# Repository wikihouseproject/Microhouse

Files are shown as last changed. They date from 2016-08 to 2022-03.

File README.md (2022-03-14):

### IMPORTANT: This repo uses an outdated, unsupported WikiHouse system. For the latest WikiHouse core system info please see the [Skylark repo](https://github.com/wikihouseproject/Skylark) and [WikiHouse guides](https://www.wikihouse.cc/guides)

# Microhouse 

MicroHouse is a high-performance, one-bed house type, designed using the WikiHouse Wren building system. It has been designed primarily for use in the UK, but could also be adapted for other countries and regions. The home can be largely self-assembled, and costs around £37-45k GBP to produce. 

These files are also intended as starter files for architects, designers, engineers and others interested in getting to know how to use the WikiHouse WREN system within a full design.

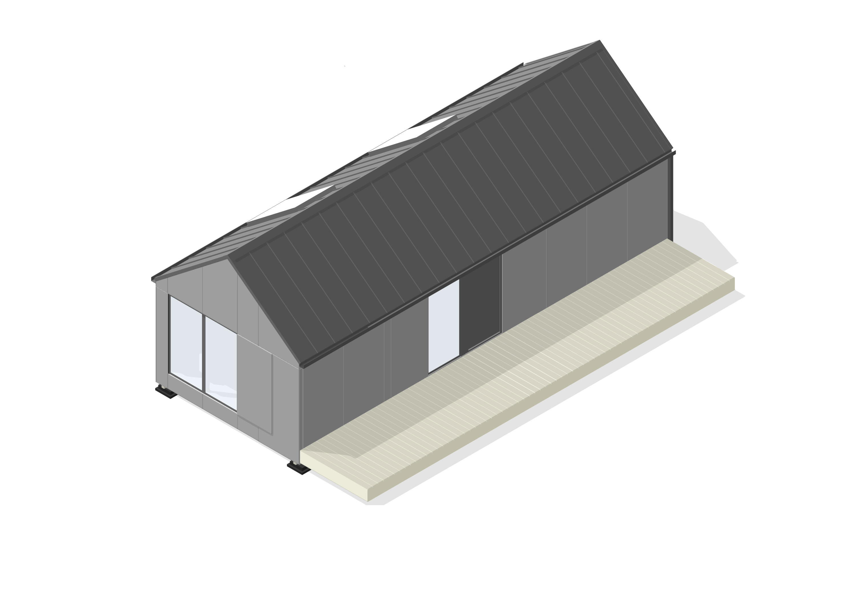
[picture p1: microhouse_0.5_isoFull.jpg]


_Project Engine: contains specification, costing/quantity information, and overall dimensions of the Microhouse design

_AssemblyManual: Detailed guide on how to put the whole thing together

_othercomponents_v0.5.dxf: Additional CNC cutting files for other components, such as fit-out furniture using SPARROW and cladding panels.

_WRENchassis_v0.5.dxf: Complete CNC cutting files for the building's structural chassis

_microhouse_0.5.skp: Sketchup 3D Model of the complete design including cladding, fitout and services

_microhouse_0.5_chassis.skp: Sketchup 3D Model of the Wikihouse structural chassis

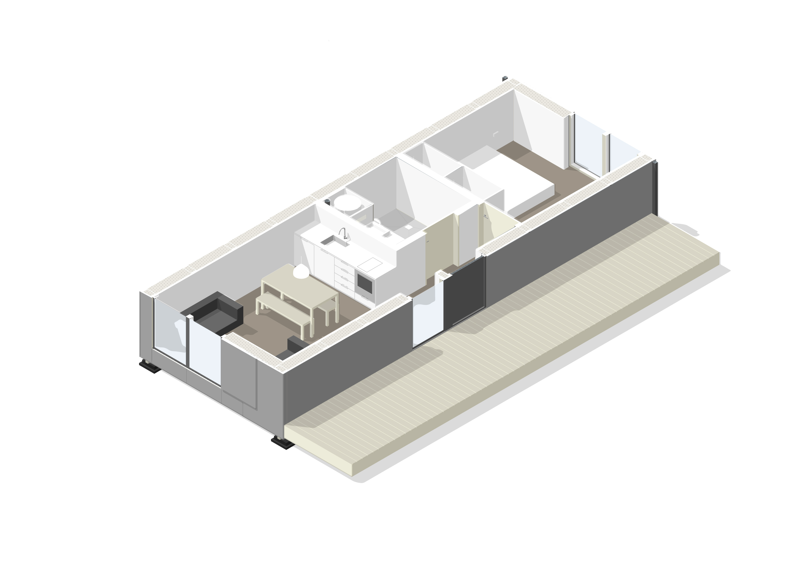
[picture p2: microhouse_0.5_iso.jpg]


<div class="sketchfab-embed-wrapper"><iframe width="640" height="480" src="https://sketchfab.com/models/ac3263022fca412c934ea9dd7c5b5521/embed" frameborder="0" allowfullscreen mozallowfullscreen="true" webkitallowfullscreen="true" onmousewheel=""></iframe>

<p style="font-size: 13px; font-weight: normal; margin: 5px; color: #4A4A4A;">
    <a href="https://sketchfab.com/models/ac3263022fca412c934ea9dd7c5b5521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" target="_blank" style="font-weight: bold; color: #1CAAD9;">Microhouse</a>
    by <a href="https://sketchfab.com/wikihouseproject?utm_medium=embed&utm_source=website&utm_campain=share-popup" target="_blank" style="font-weight: bold; color: #1CAAD9;">wikihouseproject</a>
    on <a href="https://sketchfab.com?utm_medium=embed&utm_source=website&utm_campain=share-popup" target="_blank" style="font-weight: bold; color: #1CAAD9;">Sketchfab</a>
</p>
</div>

# Terms of use

By downloading these files or information you agree to the following terms and conditions.

Information is shared without any kind of warranty or guarantee
All Information is provided ‘as is’. No representations or warranties express or implied are made regarding the Wikihouse Info, its accuracy, completeness, functionality or fitness for a particular use in a particular location.  

You are solely responsible for the use of the information
By using this information you assume full responsibility for any loss resulting from use or inability to use the Wikihouse Info, and forever releases WikiHouse Foundation or other WikiHouse users from any liability for such loss;  including but not limited to loss of profits, goodwill or assets.

You are responsible for meeting local codes and legislation
Users must satisfy themselves regarding the application of statutory requirements, local building regulations, codes, insurance certification or other requirements or recommendations relevant to the location where and materials with which they plan to build. Where required you should always seek the advice of a relevant qualified professional.

You are responsible for using the information in a safe way
 Users are responsible for ensuring that information they use or cause to be used is used in a way which is safe, and is not likely to cause harm during or after manufacturing, construction, use or disassembly.

=======
<br />This work is licensed under a <a rel="license" href="http://creativecommons.org/licenses/by-sa/3.0/">Creative Commons Attribution-ShareAlike 3.0 Unported License</a>.

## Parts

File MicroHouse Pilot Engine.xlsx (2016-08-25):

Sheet: Specification
MicroHouse
Date | 2016 |  |  |  |  |  |  |  |  |  |  |  | Estimate figure
Country | United Kingdom |  |  |  |  |  |  |  |  |  |  |  | Expected figure
Client | None |  |  |  |  |  |  |  |  |  |  |  | Actual / locked-in figure
Project use | Dwelling
Project design | Architecture 00 |  |  |  |  |  |  |  |  |  |  |  | Key action / info / check needed
WikiHouse open products used | Wren |  |  |  |  |  |  |  |  |  |  |  | Manufacturing needed
Status | Template |  |  |  |  |  |  |  |  |  |  |  | Ready to procure
Gross internal area (m2) | 37.6 m2 |  |  |  |  |  |  |  |  |  |  |  | Procured
Site address | n/a |  |  |  |  |  |  |  |  |  |  |  | Alternative option (not included in total)
MATERIAL |  |  | by Measurement |  |  |  | by Quantity |  |  | Cost |  |  | Total
Item | Specification | Suggested | Amount required | Unit | £ per SqM / M | Sub total cost | # Units per M, SqM or CuM | Total # Units | £ per Unit | TOTAL £ | VAT @ 20%
SITE & LANDSCAPE
Site clearing |  |  |  |  |  |  |  |  |  | £0.00 | £0.00
Site services installation |  |  |  |  |  |  |  |  |  | £0.00 | £0.00
Landscaping |  |  |  |  |  |  |  |  |  | £0.00 | £0.00
SUB TOTAL |  |  |  |  |  |  |  |  |  | £0.00 | £0.00
FOUNDATIONS / FOOTINGS
Pad foundations | eg. Jackpad, Swiftpad, Easypad | http://jackpad.co.uk/ | 12 |  |  |  |  | 12 | £80.00 | £960.00 | £192.00
Rail joists | 75 x 200 x 4800 treated timber | https://www.travisperkins.co.uk/Sawn-Timber-Regularised-Treated-C16-75mm-x-200mm-x-4-8m/p/322920#b | 5 |  |  |  |  | 5 | £50.00 | £250.00 | £50.00
Damp proof course roll |  | http://www.wickes.co.uk/Visqueen-Polythene-Damp-Proof-Course-300mm-x-30m/p/226581 | 22.00 | m |  |  |  | 1 | £8.32 | £8.33 | £1.67
Jointing plates | Zinc plated steel | http://www.wickes.co.uk/Wickes-Galvanised-Jointing-Flat-Plate-63x300mm/p/152829 | 4 |  |  |  |  | 4 | £2.95 | £11.80 | £2.36
Bolting brackets | Heavy Duty Angle Bracket 60mm x 60mm | http://www.screwfix.com/p/sabrefix-heavy-duty-angle-brackets-galvanised-60-x-50mm-10-pack/61576 | 16 | No. |  |  |  | 2 | £6.99 | £13.98 | £2.80
Rodent Mesh |  |  |  |  |  |  |  |  |  | £0.00 | £0.00
SUB TOTAL |  |  |  |  |  |  |  |  |  | £1,244.11 | £248.82
CHASSIS
Structural panel | WISA Spruce Plywood | 18mm x 2440 x1220 |  |  |  |  |  | 225 | £22.30 | £5,017.50 | £1,003.50
50mm screws | Prodrive Recess Countersunk Screws 200pk |  |  |  |  |  |  | 2500 | £0.00 | £0.00 | £0.00
30mm screws | Prodrive Recess Countersunk Screws |  |  |  |  |  |  | 2500 | £0.00 | £0.00 | £0.00
Underboarding | 12mm x 2400 x1200 WBP plywood |  | 39.24 | m2 |  |  |  | 10 | £16.67 | £166.67 | £33.33
SUB TOTAL |  |  |  |  |  |  |  |  |  | £5,184.17 | £1,036.83
INSULATION & AIRTIGHTNESS
Wall and roof insulation layer 1 | Soft-Fill wool/recycled - 150mm | http://www.insulationexpress.co.uk/Loft-Insulation/150mm-Earthwool-Loft-Roll-44-%28Combi-Cut%29-Loft-Insulation.htm | 42.10 | m3 |  |  |  | 11 | £24.79 | £272.69 | £54.54
Wall and roof insulation layer 2 | Soft-Fill wool/recycled - 100mm | http://www.insulationexpress.co.uk/Loft-Insulation/100mm-Earthwool-Loft-Roll-44-%28Combi-Cut%29-Loft-Insulation.htm | 58.09 | m3 |  |  |  | 10 | £26.25 | £262.50 | £52.50
Floor insulation | Cellulose loose fill | http://www.ecomerchant.co.uk/roofing/insulation/cellulose/thermofloc-loose-fill-cellulose-insulation-12kg.html | 13.32 | m3 |  |  | 3.33 | 44 | £11.99 | £531.82 | £106.36
Vapour barrier tape | Tescon | http://www.ecomerchant.co.uk/walls/airtightness-products/airtightness-tapes/pro-clima-tescon-vana.html |  |  |  |  |  | 5 | £22.50 | £112.50 | £22.50
Vapour barrier | Intello | http://www.ecomerchant.co.uk/walls/airtightness-products/internal-membranes/pro-clima-intello-plus-1-5x20m.html | 130.00 | m2 |  |  |  | 5 | £61.60 | £308.00 | £61.60
Service penetration collars
SUB TOTAL |  |  |  |  |  |  |  |  |  | £1,487.51 | £297.50
EXTERNAL WRAP
Breather membrane | Tyvek supro or similar | https://www.roofingsuperstore.co.uk/product/tyvek-supro-15m-x-50m.html | 143.00 | m2 |  |  | 0.01538 | 3 | £94.37 | £283.11 | £56.62
Heavy duty staples | Any size to fit staple gun | http://www.wickes.co.uk/Stanley-Heavy-Duty-Staples-8mm-Pack-1000/p/226059 |  |  |  |  |  | 2 | £2.90 | £5.80 | £1.16
SUB TOTAL |  |  |  |  |  |  |  |  |  | £288.91 | £57.78
CLADDING
Battens | 25mm treated batten | http://www.wickes.co.uk/Wickes-Treated-Roof-Batten-25x50x3600mm-Pack-8/p/133670 | 162 | m |  |  |  | 6 | £22.49 | £134.94 | £26.99
Opt 1 Stokboard panels | 9mm x 1220 x240 | http://www.kedel.co.uk/recycled-plastic-sheet/stokbord-recycled-plastic-sheet-board.html | 89.00 | m2 |  |  |  | 31 | £40.26 | £1,248.06 | £249.61
Opt 2 Timber cladding |  | http://www.uk-timber.co.uk/english-larch-external-half-lap-cladding-timber-p-283.html | 89.00 |  | £26.00 |  |  |  |  | £2,314.00 | £462.80
Opt 3 Steel panels | Tata colorcoat urban |  | 89.00 | m2 | £20.00 |  |  |  | £1,780.00 | £1,780.00 | £356.00
Cladding fixings |  |  |  |  |  |  |  |  | £0.00 | £0.00 | £0.00
Shutter hinges
SUB TOTAL |  |  |  |  |  |  |  |  |  | £1,383.00 | £276.60
ROOFING
Roofing Material | Steel Profile panels 514 x 2720 | TATA Colorcoat Urban | 58.09 | m2 | £20.00 |  |  | 36 | £0.00 | £1,161.83 | £232.37
Roof flashings (below rooflights) | To match roof 1330 x320
Ridge capping | Colour to match roof | TATA Colorcoat Urban | 10.8 | m |  |  |  |  | £0.00 | £0.00 | £0.00
Edge flashing | To match roof | TATA Colorcoat Urban | 10.6 | m |  |  |  |  | £0.00 | £0.00 | £0.00
Vent pipe collar
Eave fillers |  |  |  |  |  |  |  |  | £0.00 | £0.00 | £0.00
Gutter | To match roof 3m lengths | https://www.tatasteelconstruction.com/en_GB/Products/Building-envelope/Ancillaries/Fascias-and-gutters/Rainwater-Systems | 21.9 | m |  |  |  | 8 | £0.00 | £0.00 | £0.00
Gutter joins |  |  | 6
Gutter ends |  |  | 2
Gutter hoppers |  |  | 2
Gutter brackets |  |  | 44
Downpipe |  |  | 4.8 | m |  |  |  |  | £0.00 | £0.00 | £0.00
SUB TOTAL |  |  |  |  |  |  |  |  |  | £1,161.83 | £232.37
WINDOWS & DOORS
External door | ideal combi futura+i or similar | https://idealcombi.dk/Flippingbook/UK_FuturaPlus_Install2014.pdf |  |  |  |  |  | 1 | £250.00 | £250.00 | £50.00
External windows 1 | ideal combi futura+i or similar, to fit opening 2100mm x 2100mm |  |  |  |  |  |  | 2 | £1280.00 | £2,560.00 | £512.00
External windows 2 | ideal combi futura+i or similar, to fit opening 1050mm x 2100mm |  |  |  |  |  |  | 1 | £680.00 | £680.00 | £136.00
Rooflight | Openable rooflight, Internal size 920 x 1570 | https://roof-maker.co.uk/luxlite-15-70-degree-rooflight/ | 2 |  |  |  |  | 2 | £860.00 | £1,720.00 | £344.00
Expanding seal tape | Ensure correct gap size | http://www.ecomerchant.co.uk/exterior/compression-tapes/vitaseal-expanding-foam-compression-tape.html | 30 | M | £4.00 |  |  |  | £0.00 | £120.00 | £24.00
Window flashing tape |  | http://www.ecomerchant.co.uk/extoseal-encors-water-bearing-adhesive-connection-tape-with-high-adhesion-strength.html | 30 | M |  |  |  | 2.00 | £53.75 | £107.50 | £21.50
SUB TOTAL |  |  |  |  |  |  |  |  |  | £5,330.00 | £1,066.00
INTERNAL LINING
Battens for walls and ceiling | 25mm roofing batten | http://www.wickes.co.uk/Wickes-Treated-Roof-Batten-25x50x3600mm-Pack-8/p/133670 | 129 | m | £0.94 |  |  | 5 | £22.49 | £112.45 | £22.49
Gypsum wall board | Plasterboard with tapered edge | http://www.insulationexpress.co.uk/Product.asp?gclid=CPy6r9byls4CFdQ_GwodiJYNyQ | 80.99 | m2 |  |  |  | 53 | £10.51 | £557.03 | £111.41
Plasterboard screws |  |  |  |  |  |  |  |  | £0.00 | £0.00 | £0.00
Wall board filler |  |  |  |  |  |  |  |  | £0.00 | £0.00 | £0.00
Wall board tape
Floor overboarding | 18mm Chipboard flooring | http://www.wickes.co.uk/Wickes-Chipboard-Loft-Panels-Pack-3/p/116420 | 37.50 | m2 | £5.68 |  |  | 32 | £5.54 | £177.28 | £35.46
SUB TOTAL |  |  |  |  |  |  |  |  |  | £669.48 | £133.90
VENTILATION SYSTEM
MVHR Unit |  | https://www.electrical2go.co.uk/ventilation/heat-recovery/multivent/monsoon-multivent-heat-recovery-units.html |  |  |  |  |  | 1 | £661.67 | £661.67 | £132.33
Distribution splitter |  | http://www.fantronix.com/acatalog/Ventilation_Ducting_-_Y_Joint.html |  |  |  |  |  | 4 | £7.52 | £30.07 | £6.01
Ductwork | 125mm | https://www.electrical2go.co.uk/semi-rigid-aluminium-round-duct-125mm-x-3m-503230.html |  |  |  |  |  | 6 | £13.09 | £78.55 | £15.71
Room vents | 125mm | https://www.electrical2go.co.uk/125mm-air-extract-supply-valve-to-fit-pipe-round-sockets-136-5.html |  |  |  |  |  | 6 | £8.57 | £51.42 | £10.28
Duct clips |  |  |  |  |  |  |  | 16 | £1.81 | £28.96 | £5.79
SUB TOTAL |  |  |  |  |  |  |  |  |  | £850.66 | £170.13
WET SERVICES
Concealed cistern |  | http://www.wickes.co.uk/Fluidmaster-Concealed-Cistern/p/138313 |  |  |  |  |  |  |  | £50.00 | £10.00
Water supply and pipes | Push fit pipes and connectors | http://www.screwfix.com/p/floplast-pe-x-barrier-pipe-white-22mm-x-25m/38914 |  |  |  |  |  |  |  | £100.00 | £20.00
Electric water heater | Heatrae Sadia Eco 170 | http://www.directheatingsupplies.co.uk/heatrae-megaflo-eco-dd170-170l-direct-unvented-cylinder |  |  |  |  |  |  |  | £665.00 | £133.00
Drain and soil pipe parts | 110mm, black, including air admittance valve |  |  |  |  |  |  |  |  | £200.00 | £0.00
SUB TOTAL |  |  |  |  |  |  |  |  |  | £1,015.00 | £203.00
ELECTRICS & LIGHTING
Energy monitor console |  |  |  |  |  |  |  |  |  | £0.00 | £0.00
Underfloor electric heating system | Warmup | http://www.warmup.co.uk/products/electric-underfloor-heating/foil-heater-system/ | 16 | M2 | £64.00 |  |  |  |  | £1,024.00 | £204.80
Electric heating towel rail |  | http://www.bestheating.com/kudox-chrome-curved-thermostatic-electric-towel-rail-1000mm-x-500mm.html |  |  |  |  |  | 1 | £104.17 | £104.17 | £20.83
Electricals
Electricity meter |  | http://www.electricmetersales.co.uk/index.php?route=product/product&product_id=95&language=en&currency=GBP | 1 |  |  |  |  | 1 | £10.00 | £10.00 | £2.00
Energy monitor | Open Energy Monitor - emonPi | https://docs.google.com/spreadsheets/d/1gcFc0Aw81rKaCs8P6CfXkf2lCU13PUnHd0siWcLN6a4/edit | 1 |  |  |  |  | 1 | £129.20 | £129.20 | £25.84
Consumer unit |  | https://www.electrical2go.co.uk/mk-sentry-k7666smet-high-integrity-16-way-100a-fully-populated-consumer-unit.html | 1 |  |  |  |  | 1 | £60.99 | £60.99 | £12.20
Pattress box |  | https://www.electrical2go.co.uk/polar-2-gang-47mm-deep-pattress-box-with-cable-restraint.html | 8 |  |  |  |  | 8 | £1.99 | £15.93 | £3.19
Socket |  | https://www.electrical2go.co.uk/polar-switched-2-gang-13a-socket-outlet.html | 8 |  |  |  |  | 8 | £2.54 | £20.33 | £4.07
Bathroom shaving light / socket |  | http://www.diy.com/departments/smj-square-edge-white-115/230v-shaver-socket/833019_BQ.prd | 1 |  |  |  |  | 1 | £16.65 | £16.65 | £3.33
Electrical cable (240V) |  |  |  |  |  |  |  |  | £40.00 | £40.00 | £8.00
Light switch pattress box |  | https://www.electrical2go.co.uk/polar-1-gang-25mm-deep-pattress-box.html | 3 |  |  |  |  | 3 | £0.66 | £1.98 | £0.40
Light switch |  | https://www.electrical2go.co.uk/wiring-acc/sub/click-polar.html?p=2 | 3 |  |  |  |  | 3 | £0.90 | £2.70 | £0.54
Bathroom light switch |  | http://www.diy.com/departments/propower-6a-2-way-white-pull-switch/833006_BQ.prd | 1 |  |  |  |  | 1 | £3.33 | £3.33 | £0.67
LED fixed light |  | http://www.diy.com/departments/genlis-white-spotlight/679339_BQ.prd | 12 |  |  |  |  | 12 | £12.50 | £150.00 | £30.00
Kitchen unit lighting kit | IKEA |  | 1 |  |  |  |  | 1 | £25.00 | £25.00 | £5.00
Burglar alarm |  | http://www.screwfix.com/p/yale-hsa6200-wireless-alarm-kit/97114?kpid=97114 | 1 |  |  |  |  | 1 | £83.33 | £83.33 | £16.67
Outdoor light |  | http://www.diy.com/departments/blooma-thetis-black-external-wall-light/881940_BQ.prd | 1 |  |  |  |  | 1 | £6.67 | £6.67 | £1.33
 |  |  |  |  |  |  |  |  | £0.00 | £0.00 | £0.00
SUB TOTAL |  |  |  |  |  |  |  |  |  | £1,694.28 | £338.86
BATHROOM & KITCHEN
Kitchen units
Kitchen base cabinets | 600x600x800 | IKEA | 4 |  |  |  |  | 4 | £50.00 | £200.00 | £40.00
Kitchen upper cabinets | 600x600x800 | IKEA | 4 |  |  |  |  | 4 | £35.00 | £140.00 | £28.00
Kitchen worktop | 2414 length | IKEA | 1 |  |  |  |  | 1 | £50.00 | £50.00 | £10.00
Kitchen splashback | 50x60 panels and rail | IKEA | 4 |  |  |  |  | 1 | £50.00 | £50.00 | £10.00
Kitchen appliances | Sink, hob, cooker, fridge, tap | IKEA | 1 |  |  |  |  | 1 | £583.33 | £583.33 | £116.67
Washer / dryer |  |  |  |  |  |  |  |  | £0.00 | £0.00 | £0.00
Bathroom Basin |  | http://www.ikea.com/gb/en/catalog/products/60304715/ |  |  |  |  |  | 1 | £50.00 | £50.00 | £10.00
Bathroom tap |  | http://www.ikea.com/gb/en/catalog/products/00281302/ |  |  |  |  |  | 1 | £41.67 | £41.67 | £8.33
Shower head and controls |  |  |  |  |  |  |  | 1 | £0.20 | £0.00 | £0.00
WC | Standing, dual flush (no cistern) | http://www.screwfix.com/p/orlando-back-to-wall-toilet-dual-flush/5416f |  |  |  |  |  | 1 | £165.83 | £165.83 | £33.17
Wet room liner |  | http://www.wetroomsdirect.net/riw-tilesafe-waterproofing.html |  |  |  |  |  |  | £0.00 | £0.00 | £0.00
Wet room floor board |  | http://www.wetroomsdirect.net/akw-duraform-floor-former.html |  |  |  |  |  |  |  | £0.00 | £0.00
Bathroom wall finish |  | http://www.multipanel.co.uk/products/walls/economy-wall-panel-range |  |  |  |  |  |  |  | £0.00 | £0.00
Bathroom cabinets |  |  |  |  |  |  |  |  |  | £0.00 | £0.00
Bathroom cabinets materials | 18mm melamine faced plywood | http://www.slhardwoods.co.uk/products/sheet-material/melamine-faced-mdf/white-melamine-faced-mdf-2440-1220mm |  |  |  |  |  | 10 | £29.17 | £291.67 | £58.33
Cabinet hinges | 14 | http://www.screwfix.com/p/hafele-soft-close-clip-on-concealed-hinges-110-64mm-2-pack/9205j |  |  |  |  |  | 7 | £3.33 | £23.28 | £4.66
Cupboard shelf pegs |  | http://www.screwfix.com/p/steel-shelf-support-100-pack/55545?kpid=55545 |  |  |  |  |  | 1 | £6.99 | £6.99 | £1.40
Bumper push latch | 7 | http://www.screwfix.com/p/bumper-push-latch-grey-12mm-5-pack/13146 |  |  |  |  |  | 2 | £8.33 | £16.65 | £3.33
Mirror | 6mm x 1380 x 1900 | https://www.fittedmirrorsandglass.co.uk/?gclid=CJfagvOPo84CFdQ_Gwodd5oIIg |  |  |  |  |  | 1 | £157.08 | £157.08 | £31.42
SUB TOTAL |  |  |  |  |  |  |  |  |  | £840.83 | £168.17
INTERNAL DOORS, FIT OUT & FINISHES
Wardrobe kit materials | 18mm melamine faced plywood | http://www.slhardwoods.co.uk/products/sheet-material/melamine-faced-mdf/white-melamine-faced-mdf-2440-1220mm |  |  |  |  |  | 10 | £29.17 | £291.67 | £58.33
Internal doors
Internal doors materials | 18mm twin birch faced plywood, 1220 x 2440 | http://www.lathamtimber.co.uk/downloads/james-latham-product-price-guide-65.pdf |  |  |  |  |  | 5 | £43.10 | £215.50 | £43.10
Dowels | 8mm x 30mm | http://www.diy.com/departments/bq-dowel-8mm-x-30mm-pack-of-25/243300_BQ.prd |  |  |  |  |  | 1 | £1.82 | £1.82 | £0.36
Cork board | 5mm thick, any size sheet | https://www.amazon.co.uk/Board-Sheet-High-Quality-Flexible-Antistatic/dp/B00C75Y3O0 |  |  |  |  |  | 1 | £19.99 | £19.99 | £4.00
Hinges | 102x75x3mm | http://www.diy.com/departments/stainless-steel-grade-11-ball-bearing-hinge-pair-of-2/29418_BQ.prd |  |  |  |  |  | 3 | £7.02 | £21.06 | £4.21
Tubular latch | 64mm, steel | http://www.diy.com/departments/bq-tubular-latch-l64mm/171957_BQ.prd?icamp=recs |  |  |  |  |  | 2 | £3.19 | £6.38 | £1.28
Handle set | Brushed stainless steel | http://www.diy.com/departments/bq-satin-stainless-steel-effect-straight-internal-external-lever-latch-door-handle-pack-of-2/190881_BQ.prd |  |  |  |  |  | 2 | £14.17 | £28.34 | £5.67
WC Tubular deadbolt |  | http://www.doorhandlecompany.co.uk/architectural-64mm-2.5-inch-tubular-deadbolt-silver-or-brass-2114/ |  |  |  |  |  | 1 | £4.95 | £4.95 | £0.99
WC turn and release |  | http://www.morehandles.co.uk/zoo-5mm-disabled-turn-and-release-with-indicator-zcs2006i.html |  |  |  |  |  | 1 | £7.00 | £7.00 | £1.40
Bathroom tiles |  |  |  |  |  |  |  |  | £0.00 | £0.00 | £0.00
Paint |  |  |  |  |  |  |  |  | £0.00 | £0.00 | £0.00
Floor finishes |  |  | 75.34 | m2 |  |  |  |  | £0.00 | £0.00 | £0.00
SUB TOTAL |  |  |  |  |  |  |  |  |  | £596.70 | £119.34
MATERIALS TOTAL |  |  |  |  |  |  |  |  |  | £21,746.49 | £4,349.30
PRODUCTION COSTS
Manufacture
Chassis CNC manufacture | Minimum 8ft x 4ft CNC 3-axis router with standard CAM software. |  |  |  |  |  |  | 200 | £25.00 | £5,000.00 | £1,000.00
Doors CNC manufacture | Minimum 8ft x 4ft CNC 3-axis router with standard CAM software. |  |  |  |  |  |  | 5 | £25.00 | £125.00 | £25.00
Wardrobe CNC manufacture | Minimum 8ft x 4ft CNC 3-axis router with standard CAM software. |  |  |  |  |  |  | 10 | £25.00 | £250.00 | £50.00
Bathroom cabinets CNC manufacture | Minimum 8ft x 4ft CNC 3-axis router with standard CAM software. |  |  |  |  |  |  | 10 | £25.00 | £250.00 | £50.00
Cladding CNC manufacture | Minimum 8ft x 4ft CNC 3-axis router with standard CAM software. |  |  |  |  |  |  | 31 | £25.00 | £775.00 | £155.00
Design checking fee |  |  |  |  |  |  |  |  |  | £0.00 | £0.00
Structural engineer checking fee |  |  |  |  |  |  |  |  |  | £0.00 | £0.00
Electrical installation |  |  |  |  |  |  |  |  |  | £600.00 | £120.00
Plumbing installation |  |  |  |  |  |  |  |  |  | £600.00 | £120.00
Foundations building |  |  |  |  |  |  |  |  |  | £0.00 | £0.00
Building assembly |  |  |  |  |  |  |  |  |  | £0.00 | £0.00
CNC parts delivery |  |  |  |  |  |  |  |  |  | £0.00 | £0.00
Warranty (if applicable) |  |  |  |  |  |  |  |  |  | £0.00 | £0.00
Building control inspector |  |  |  |  |  |  |  |  |  | £0.00 | £0.00
Insurance |  |  |  |  |  |  |  |  |  | £0.00 | £0.00
Project contingency budget |  |  |  |  |  |  |  |  |  | £1,087.32 | £217.46
Optional contribution to WikiHouse Foundation |  |  |  |  |  |  |  |  |  | £0.00 | £0.00
 |  |  |  |  |  |  |  |  |  | £8,687.32 | £457.46
SINGLE UNIT TOTAL |  |  |  |  |  |  |  |  |  | £30,433.81 | £6,086.76 | £36,520.57

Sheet: Cladding Materials Options
Material | Manufacturer | Description | Link | Price Per Sqm | Labour
Brick/Stone Veneer
Corium clip-on bricks | Wienerberger | Brick slip tiles fix mechanically to a HPS200 galvanised steel backing section | http://www.wienerberger.co.uk/what-is-corium.html?lpi=1366208067822 | ? | Medium. Clip-on with mortar
Cement Board
Fibre-cement panels | Equitone Linea | Fibre cement composite rainscreen, grooved finish | http://www.equitone.com/ | ? | Low. Panelised, screw fix
Metal Cladding
Colourcoat Urban | TATA steel | Secret fix standing seam roof and wall steel cladding, seamlessy clip together. | http://www.colorcoat-online.com/en/products/exterior-products/colorcoat-urban | ? | Low. Panelised, clip & screw fix

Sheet: MicroHouse Unit Summary
SYHA PILOT - UNIT SUMMARY
Unit Details |  | Plot Dimensions |  |  | Unit Dimensions - Centrelines |  |  |  |  | Unit Dimensions - Internal |  |  | Unit Dimensions - External |  |  | Unit Total
Plot Number | No. of Floors | Plot Width | Plot Length | Plot Area (m2) | Width | Length | No. of Bays | Roof Height | 1st Floor Height | Internal Width (Lining+Battens+Chassis) | Internal Length (Lining+Battens+Chassis) | Ceiling Height (Lining+Battens+Chassis) | External Width | External Length | External Height | Unit Internal Area GIA (m2) | Unit External Area Footprint (m2)
PLOT 1 | 1 | 5700 | 17000 | 96.90 | 3900 | 10800 | 9 | 3900 | 0 | 3553 | 10603 | -347 | 4486 | 11250 | 4486 | 37.67 | 50.47
Total Area (m2) |  |  |  | 96.90 |  |  |  |  |  |  |  |  |  |  |  | 37.67 | 50.47
 |  |  |  |  |  |  |  |  |  |  |  |  |  |  | Site Coverage |  | 52.08%

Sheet: Dashboard
PLOT 1 | - | INPUT PARAMETERS |  |  | PLOT 1 | OUTPUT PARAMETERS
Building Dimensions | Centre-line Dimension | Units | Internal Dimension (mm) | External Dimension (mm) | Building Area | Value | Units
Width | 3900 | mm | 3553 | 4486 | Footprint Area | 50.47 | m2
Length | 10800 | mm | 10603 | 11250 | Ext Surface Area | 185.44 | m2
Height - Left Wall | 2400 | mm |  |  | Int Floor Area | 75.34 | m2
Height - Right Wall | 2400 | mm |  |  | Int Wall Area | 88.89 | m2
Height - Roof Apex | 3900 | mm |  |  | Int Roof Area | 49.24 | m2
Roof Apex offset | 0 | mm |  |  | Area of Openings | 14.66 | m2
Column Postion (From Left) | 0 | mm |  |  | End wall area | 10.41 | m2
1st Floor Height | 0 | mm |  |  | Thermal Analysis | Value | Units
 |  |  |  |  | Insulation Volume | 42.096 | m3
Building Form | Selection |  |  |  | Insulation Conductivity |  | m2K/W
roofPoints | 1 |  |  |  | Wall Thermal Conductivity |  | W/m2k
Column? | FALSE |  |  |  | Roof Thermal Conductivity |  | W/m2k
Two Storey? | FALSE |  |  |  | Internal Air Volume |  | m3
Mezzanine? | FALSE
 |  |  |  |  | Materials | Quantity (Total) | Units | Depth (mm) | Spec | Density (kg/m3) | Total Mass(kg)
Macro Parameters | Value (mm) |  |  |  | Plywood - Portal Frame | 2.639 | m3 | 18 | WISA Structural spruce ply | 510 | 1,346
Bays | 9 | bays |  |  | Plywood - Connecters/Sheathing | 4.813 | m3 | 18 | WISA Structural spruce ply | 510 | 2,454
Beam Width | 150 | mm |  |  | Plywood - End Walls | 0.557 | m3 | 18 | WISA Structural spruce ply | 510 | 284
Connector Grip Length | 80 | mm |  |  | Internal lining - Plasterboard | 80.988 | m2 | 9.5 | Refer to spec | 510 | 392
Connector Slot length (Floor) | 80 | mm |  |  | Floor underside panels (http://www.wickes.co.uk/Wickes-Non-Structural-Hardwood-Plywood-5-5x1220x2440mm/p/110117) | 39.236 | m2 | 6 | Refer to spec | 510 | 120
Connector Slot length (Wall) | 90 | mm |  |  | Wall Cladding | 83.991 | m2 |  | Refer to spec | 510 | 0
Fin Depth | 250 | mm |  |  | Screws (http://www.wickes.co.uk/Wickes-External-Grade-Screws-Green-No-10x50mm-Pack-20/p/510124) | 1656.000 | no. | 50 | Refer to spec | 0.0058 | 10
Frame Grips length | 180 | mm |  |  | Insulation (Total External) (http://www.eksonser.com/cellulose.html) | 42.096 | m3 | 250 | Refer to spec | 30 | 1,263
Gauge | 1200 | mm |  |  | Roof Cladding | 58.092 | m2 |  | Refer to spec | 510 | 0
Ply Thickness | 18 | mm |  |  | External Membrane (http://www.dupont.co.uk/products-and-services/construction-materials/tyvek-building-envelope/brands/tyvek-breather-membrane/products/tyvek-uv-facade-rainscree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) | 140.597 | m2 |  | Refer to spec
Sheet Length | 2400 | mm |  |  | Internal Membrane (http://www.dupont.co.uk/products-and-services/construction-materials/tyvek-building-envelope/brands/airguard-vapour-control-layer/products/airguard-reflective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) | 156.333 | m2 |  | Refer to spec
Sheet Width | 1200 | mm |  |  | Vertical Battens |  | m |  | Refer to spec | 500
Spacing Ratio | 300 | mm |  |  | Horizontal Battens |  | m |  | Refer to spec | 500
Tolerance | 0 | mm |  |  | Guttering | 21.900 | m |  | Refer to spec
Tool size (Dogbones) | 10 | mm |  |  | Downpipes | 4.800 | m |  | Refer to spec
 |  |  |  |  |  |  |  |  |  |  | 5,870
External Cladding | Value (mm)
Cladding Thickness | 43 | mm |  |  | Estimates | Value | Units | Depth |  | Equation
Horizontal Batten Width | 32 | mm |  |  | No. of Chassis Plywood Sheets | 200 | Sheets | 18 | WISA Structural spruce ply | APPROX ONLY
Vertical Batten Width | 75 | mm |  |  | Volume - Single Plywood Sheet | 0.0535824 | m3
 |  |  |  |  | Average CNC Waste Factor | 0.30
Internal Lining | Value (mm)
Plasterboard Thickness | 9.5 | mm |  |  | Estimated Cutting Time | 0 | minutes |  |  | Time/sheet x sheets
Batten Width | 34 | mm |  |  | People Required / Single Frame | 5 | Humans |  |  | 25kg / person
Batten Height | 21 | mm |  |  | Misc items | Value | Units
 |  |  |  |  | Sink | 10 | Kg
Stair Parameters | Value (mm) |  |  |  | Gutter and rainwater pipes | 12 | Kg
Stair Length |  | mm |  |  | Instant boiler | 5 | Kg
Tread/Going Length |  | mm
Riser Height |  | mm
Cladding Material | Material
North Elevation
East Elevation
South Elevation
West Elevation

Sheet: Window/Door
PLOT 1 | WINDOW, ROOF LIGHT & DOOR SCHEDULE
LOCATION - Front = Entrance Door | WINDOW / DOOR | Bay Location | Level | Side - A(left) / B(Right) / C(UpperLeft) / D(UpperRight) | Opening width (+/- 5mm) | Opening height (+/- 5mm) | Unit width (mm) | Unit height (mm) | Height from junction centreline | Distance from left | Height from floor | Perimeter length | Opening Area (m2) | Width to packer | Spec | Link | Price (Ex VAT)
East Elevation (End wall) | WN-01 | RW | GF | A | 2118 | 2118 | 2113 | 2113 | 0 | 0 |  | 8452 | 4.485924 |  | Fixed
North Elevation (Front)
North Roof | RL-01 | 02 | RF | A | 1050 | 1695 | 1045 | 1690 | 228.8 | - |  | 5470 | 1.77975 |  | Fixed
 | RL-02 | 05 | RF | A | 1050 | 1695 | 1045 | 1690 | 228.8 | - |  | 5470 | 1.77975 |  | Fixed
South Elevation (Rear) | DR-01 | 04 | GF | B | 1050 | 2100 | 1045 | 2095 | 125 | - |  | 6280 | 2.205 |  | Opener
 | WN--02 | 03 | GF | B | 1050 | 2100 | 1045 | 2095 | 125 | - |  | 6280 | 2.205 |  | Fixed
South Roof
West Elevation | WN-03 | FW | GF | A | 2118 | 2118 | 2113 | 2113 | 0 | 0 |  | 8452 | 4.485924 |  | Fixed
 |  |  |  |  |  |  |  |  |  |  |  | WINDOW AREA (m2): | 12.46
 |  |  |  |  |  |  |  |  |  |  |  | DOOR AREA (m2): | 2.21

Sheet: Laser Scale Model
MicroHouse Model
Date | 2016 |  |  |  |  |  |  |  |  |  |  |  | Estimate figure
Country | United Kingdom |  |  |  |  |  |  |  |  |  |  |  | Expected figure
Client | None |  |  |  |  |  |  |  |  |  |  |  | Actual / locked-in figure
Project use | Demo
Project design | Architecture 00 |  |  |  |  |  |  |  |  |  |  |  | Key action / info / check needed
WikiHouse open products used | Wren |  |  |  |  |  |  |  |  |  |  |  | Manufacturing needed
Status | Template |  |  |  |  |  |  |  |  |  |  |  | Ready to procure
Approx Size | 1:6 scale |  |  |  |  |  |  |  |  |  |  |  | Procured
Site address | n/a |  |  |  |  |  |  |  |  |  |  |  | Alternative option (not included in total)
MATERIAL |  |  | by Measurement |  |  |  | by Quantity |  |  | Cost |  |  | Total
Item | Specification | Suggested | Amount required | Unit | £ per SqM / M | Sub total cost | # Units per M, SqM or CuM | Total # Units | £ per Unit | TOTAL £ | VAT @ 20%
CHASSIS
3mm BIRCH ply | 3mm x 600 x 400mm | https://www.kitronik.co.uk/3214-15mm-birch-laser-plywood-600mm-x-400mm-sheet.html | 60 | Sheets |  |  |  | 60 | £2.70 | £162.00 | £32.40
1.5mm BIRCH ply | 1.5mm x 600 x 400mm | https://www.kitronik.co.uk/3214-15mm-birch-laser-plywood-600mm-x-400mm-sheet.html | 60 |  |  |  |  | 60 | £0.00 | £0.00 | £0.00
 |  |  |  |  |  |  |  |  | £0.00 | £0.00 | £0.00
 |  |  |  |  |  |  |  |  | £0.00 | £0.00 | £0.00
SUB TOTAL |  |  |  |  |  |  |  |  |  | £162.00 | £32.40
FABRICATION - LASER
Manufacture | 600mm x 400mm |  |  |  |  |  |  |  |  | £0.00 | £0.00
 |  |  |  |  |  |  |  |  |  | £0.00 | £0.00
 |  |  |  |  |  |  |  |  |  | £0.00 | £0.00
SUB TOTAL |  |  |  |  |  |  |  |  |  | £0.00 | £0.00
POSTAGE & SHIPPING
Packaging |  |  |  |  |  |  |  | 1 | £0.00 | £0.00 | £0.00
Stamps |  |  |  |  |  |  |  | 5 | £0.00 | £0.00 | £0.00
SUB TOTAL |  |  |  |  |  |  |  |  |  | £0.00 | £0.00
 |  |  |  |  |  |  |  |  |  | £162.00 | £32.40
SINGLE UNIT TOTAL |  |  |  |  |  |  |  |  |  | £162.00 | £32.40 | £194.40

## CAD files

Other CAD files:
MicroHouse_othercomponents_v0.5.dxf
Microhouse_WRENchassis_v0.5.dxf

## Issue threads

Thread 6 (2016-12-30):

Onshape compatible file formats

paulocoghi, 2016-12-30:
From an open perspective, it would be interesting to share files in a format that everyone could open and edit, without having to pay for it.

Since Onshape has a free plan (complete and full-featured) and its online, everyone using any operating system will be able to work with WikiHouse, for free.

Onshape is compatible with many know formats, but unfortunately it isn't with Sketchup files.

theoryshaw, 2016-12-30:
I would suggest an openBIM standard like IFC....

- https://en.wikipedia.org/wiki/Industry_Foundation_Classes
- http://www.buildingsmart-tech.org/specifications/ifc-overview

.IFC files can be opened by most major [BIM](https://en.wikipedia.org/wiki/Building_information_modeling) programs...
http://www.buildingsmart-tech.org/implementation/implementations

Having the content in a proprietary format (onshape, sketchup, etc.), even though the program is 'free' to use, you risk vendor lock-in in the future.

paulocoghi, 2016-12-31:
@theoryshaw Thanks for the reply!

I am with you, and my suggestion isn't to use Onshape's propetary format, but a widely used format (like the one you mentioned).

I just mentioned Onshape because it is one of the few quality software that, in addition to have a free plan, it is multi-platform (and I reaffirm that my suggestion is not about it's proprietary format, but many konw formats that Onshape also opens).

paulocoghi, 2016-12-31:
It is still difficult to find quality softwares in the area of architecture and CAD in general, which are good, have a free option and are really cross-platform.

From this point of view, Onshape is a rare case.

claytonprest, 2017-01-25:
Hi @paulocoghi @theoryshaw . Thanks for comments, and you make a valid point. We have used sketchup as the default format to date as that's where much of the earlier Wikihouse contributions were modelled. But I agree that this no longer makes sense, and as the Wikihouse Foundation we can provide a better range of CAD file formats for each release. Would adding .obj, .dwg and .ifc models to each repository help you get started?

Onshape is a good tool, and perhaps a better online platform for sharing models and collaborating on design. We definitely encourage anyone to take any Wikihouse forward in Onshape and other open tools.

However for rules-based building systems like WREN we think there are limitations to common CAD software. The Wikihouse Foundation is currently developing a web-based platform for open digital construction, to make the design and development of Wikihouse technologies much much easier. It will have a front end for architectural design and back end for system R&D, which will be closer to coding than CAD, but still intuitive for visually-minded designers to use. Watch this space :)

paulocoghi, 2017-01-25:
> The Wikihouse Foundation is currently developing a web-based platform for open digital construction, to make the design and development of Wikihouse technologies much much easier. It will have a front end for architectural design and back end for system R&D, which will be closer to coding than CAD, but still intuitive for visually-minded designers to use.

@claytonprest That would be amazing! And certainly much more effective than making the files available in other formats.

tamg, 2017-01-25:
@claytonprest a web based open source CAD construction would be a game changer!

zawsx, 2018-12-13:
I'd like to use the files here so looked at Onshape - they do not have a free plan. They have a student plan, limited to those at college or university. [Pricing plan page here](https://www.onshape.com/cad-pricing). So I can't use it.

jedroach, 2018-12-13:
Though they have made it non obvious and perhaps they may eliminate it, the free plan does still exist.
[https://www.onshape.com/products/free](https://www.onshape.com/products/free)

zawsx, 2018-12-13:
> Though they have made it non obvious and perhaps they may eliminate it, the free plan does still exist.
> https://www.onshape.com/products/free

Thanks! I really hard to find this link, knowing it must exist, but couldn't. Agree they could drop it at any time, so wonder if it's worth the intellectual property investment of learning something that can only serve to profit the generators of closed source as, when they drop it, we'll be obliged to pay for a licence (which I simply could not afford).
Maybe the best response is to support open source CAD, hoping they'll implement support for open BIM and 'open' or defacto file formats. Anyone any experience of open source software that supports (or could support) the files in this repo and the design language?

JohnTordur, 2019-02-17:
Hello, I know of a design tool called OpenSCAD, its commonly used in the 3D printing world for parametrizing parts. The format is open, the only disadvantage would be that it only exports to .stl. http://www.openscad.org/

hhassey, 2019-03-20:
FreeCAD is the way to go, OnShape is not FreeSorftware so why bother?

IFC as an industry standard could also be used.

zawsx, 2019-03-22:
Not sure how alive this thread is @hhassey - last code update was early 2018, a decade ago in internet time.
I looked at IFC, seems fine as an idea, not sure why it's needed,. there seems  a whole standards industry for BIM that has nothing to do with the real world - where are the open source 3D building diagrams that are the logical result of conformance to Building Standards? Couldn't find a list of software that exports or imports in the IFC format.

theoryshaw, 2019-03-22:
http://www.buildingsmart-tech.org/implementation/implementations

List of software that uses IFC.

zawsx, 2019-03-23:
Thanks @theoryshaw it's really difficult working through that list. Guess like some the aim is an open source toolchain to improve the basic design, visualise by overlay onto maps and plans, 'fly through', test and measure conformity via BIM tools in a reciprocal manner.
Almost all the IFC-format-supporting software from this helpful list [http://www.buildingsmart-tech.org/implementation/implementations](http://www.buildingsmart-tech.org/implementation/implementations) is closed source.
Thought I'd found the one ([openstudio.net](https://www.openstudio.net) but it needs Sketchup, which is closed source and not free.

theoryshaw, 2019-03-23:
For me, it's more important to build off open protocols... then everyone can use their own tool of choice.

Just like you're able to use the browser of your choice--as the internet built on open protocols.

For me, the content should not be reliant on the tool that created it--whether open source or proprietary.

hhassey, 2019-03-23:
@zawsx @theoryshaw FreeCAD is free software (LGPL) and is IFC capable through the IFCOpenShell [https://github.com/IfcOpenShell/IfcOpenShell](IfcOpenShell) It is being heavily developed and it will not surprise me when in the near future it ships with IFC capabilities right out of the box.

Other possible formats are STEP (which is great for 3D and CAM, but not that great for BIM)

Thoughts?

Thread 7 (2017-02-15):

Possible minor issues with Microhouse_WRENchassis_v0.5.dxf

skovholt, 2017-02-15:
Hi,

looking closely at the dxf there seems to be a gap between the connection points in frame (between FRA-A/F6 and FRA-A/F1), it's quite small so I suppose it doesn't pose any problem (see picture). Also FRA-A/S10/IN as well as FRA-A/S10/EX seems to be absent in the dxf? Also there are no pegs in that DXF, or MicroHouse_othercomponents_v0.5.dxf as far as I can tell (if the kind pictured should be used with this design?).

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

We plan to make a section of the Microhouse in Norway for an educational project (using 18mm OSB), are there any other things one should be aware of using Microhouse_WRENchassis_v0.5.dxf for cnc-cutting?

claytonprest, 2017-02-15:
Hi @skovholt
Thanks for raising these. I've had look at the DXF in regards to your queries.

1. There should be a gap of 0.75mm between FRA-A/F6 and FRA-A/F1. This is an offset of the original outline to create some tolerance for the assembly. Are you getting a gap any bigger than that?

2. I realise this is an error in the microhouse_0.5_chassis.skp sketchup model. If you refer to the Assembly Guide in this repo you'll see there shouldn't be any FRA-A/S10/IN or FRA-A/S10/EX parts. So the DXF cutting file is correct, and so I have updated the sketchup model now to match.

3. Good question on the pegs. No these pegs are no longer part of the latest WREN system and aren't required in the design. So hopefully there should be less fiddly parts.

Sounds exciting. Will just be building the chassis for your project? If you're looking at finishes and cladding you can download the Engine spreadsheet there's a good spec of others materials and approximate costs. We're currently doing some development on the gable end wall system of the chassis, so those elements will hopefully be updated in the next few weeks.

Let us know how it goes, and feel free to post any photos etc to the Wikihouse Community Slack group.

skovholt, 2017-02-16:
Hi @claytonprest,

thanks for your swift reply.

1.  Just downloaded from repository now, and it seems I mistakenly might have moved some points around in my local dxf, it seems right now. Sorry about that.

Another thing regarding offsets; in the dxf for studio (Studio_1.dxf), there was a note on offsets, which read "0.25mm inset outer edges inwards (making piece smaller)". So the offset on all outer pieces in Microhouse_WRENchassis_v0.5.dxf is applied as 0.75mm? Also in Studio_1.dxf: "1mm offset inner slot holes" Are those also adjusted in Microhouse_WRENchassis_v0.5.dxf?

2. Great, thanks for clarifying.

3. Excellent.

Initially we will just build parts of a chassis, we might clad it at a later time. Also in this first run we won't make the end wall, so then we might be able to use the new system for gable and end wall when they are updated.

Joined the slack group now, and will keep you updated with some pictures when we get to that stage.

claytonprest, 2017-02-16:
@skovholt No problem, good to have that sorted. You're right that the inset on outer edges should be 0.25mm as a general rule of thumb, but you've spotted a small anomaly at the dovetail joint locations in the F parts which already have a slight tolerance between each part.

This is small unnecessary gap and shouldn't make much difference if you removed it. But it's always worth test cutting a few pieces with your chosen material to ensure everything is fitting tightly, and not too tight that you can't easily mallet together! You can then adjust the cutting files to suit before doing a full production run.

skovholt, 2017-02-16:
@claytonprest Noted, thanks!

Closed 2017-02-16.

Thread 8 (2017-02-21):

Some other questions regarding Microhouse_WRENchassis_v0.5.dxf

skovholt, 2017-02-21:
Hi,

some additional questions regarding Microhouse_WRENchassis_v0.5.dxf:

1
Single puzzle joints in spacer components: when i put these 0.5mm appart there seems to be some extra spacing on the sides (about 1.9mm). Is it intentional?
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

2
FRA-A/S3/EX seems to be missing in the dxf?

3
I guess there should there be dogbones in this location on spacers? Picture is from full scale test of some pieces and not screwed together.

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

claytonprest, 2017-02-28:
Hi @skovholt

1. This is the same condition as the dovetail joints in the Fins, there is a small offset of 0.5mm applied the joint before the 0.25mm general in-set on all parts. It's not needed, and shouldn't make much difference. You can choose to leave it as is or reduce it for a tighter fit, it's worth checking how it fits with your material and full-scale tests first.

2, You're right, FRA-A/S3/EX was mistakenly labelled in the .dxf cutting file. I've fixed this now, so should be all correct in the latest version.

3. Yes, there should be 'dog-bone' notches in the internal corners here, and is an error on our part. I've modelled these now, and the most recent update to the .dxf in the Microhouse repo now includes these pockets. If you have already cut parts like above, a quick rub with a file should allow all pieces to fit.

Thanks again for raising these issues. It's super important to have feedback like this from you and others in the community. Hope the rest of your project is going well?

skovholt, 2017-03-01:
Hi @claytonprest, thanks for your feedback

1. Ok, we left it with the spacing as in the dxf, and it seems to work ok as is.

3. Yes, I became aware of this a bit into production, so I fixed it on some pieces, the rest we can fix manually.

The project has so far gone quiet smoothly, we'we milled parts for 4 frames/spacers/reinforcers/connectors, with roof, wall and some flooring in 18mm OSB.  We don't have a vacuum table for our cnc, but used composite brad nails with good results. Don't know yet when it will be assembled. The production is commissioned by @twengel (Slack) and has been cnc cut at http://fellesverkstedet.no/ a production space and fablab in Oslo.

Closed 2017-03-01.

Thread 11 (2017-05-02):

Part mismatch between instruction PDF and DXF file

alexcg1, 2017-05-02:
DXF file: Microhouse_WRENchassis_v0.5.dxf
PDF file: MicroHouse_AssemblyManual_v1_sm.pdf

Trying to make a small sample section of Wikihouse and turns out the part labels in the instructions are different to the DXF.

For example:
* In the PDF, R2 has no "crucifix" cut into it and an obtuse angle. In the DXF, FRA-A/R2 has a crucifix and has a 90 degree angle. It's just a reversed FRA-A/R1
* In PDF, R3 has a notch on one side. In DXF, FRA-A/R3 has notch on the other side

I'm guessing it's not the parts themselves that are wrong, but the labels. From looking at the pieces themselves:
* PDF R2 == DXF FRA-A/R3
* PDF R3 == DXF FRA-A/R4

Can anyone else confirm?

[MicroHouse_AssemblyManual_v1_sm.pdf](https://github.com/wikihouseproject/Microhouse/files/969686/MicroHouse_AssemblyManual_v1_sm.pdf)

HarryKnight, 2017-05-08:
@claytonprest would be best to confirm this.

claytonprest, 2017-05-24:
Hi @alexcg1 Thanks for spotting this! Like you say, it's just a mismatch in labels.

Closed 2017-10-10.

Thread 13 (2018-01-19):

Virtual Test Build Results

jedroach, 2018-01-19:
Hello,

I completed a virtual test build of the MicroHouse in OnShape.  See the results here:

[https://cad.onshape.com/documents/05ee4ed8debb791b540e74de/w/b34eb3abf186ae8e86ecf274/e/0e3aef5ccf0cf29e489f504f](url)

This build was done using Microhouse_WRENchassis_v0.5.dxf as the source data.  The assembly was done using the manual firstly and then referring to the SketchUp model to fill in the blanks.  I only created unique parts in the part studios and then used patterning features within the assembly to create the rest of the parts.  So, I did not do a strict accounting of part quantities, but I did find some quantity errors which I noted below.

Issues:
I could not open MicroHouse_othercomponents_v0.5.dxf with any of the half dozen programs I tried.
Step 0:  What size should the rails be?
Step 2 and 3: F2 and F6 labels are swapped.  ( I think F1 should be changed and F2 and F6 should be the same part.)
Step 4:  SKI/B, C, and D are left out of the manual and SKI/B needs to be installed on the first frame you raise.
F3 = F5, R1 = R2, R3 = R5
Step 7: Panel 009:  ROOF/4 should be labeled EXWALL/4
Step 9: The UNDER-X pieces need labels.  There should be a FLOOR/4 for where UNDER/4 goes.
Step 10:  I think CEIL/2 and CEIL/4 are the same as ROOF/5, but quantity is 2 short.
Add notes for interior and exterior trim pieces.
Step 11b:  END/2/F1 is missing from DXF. It is the same as END/1/F1, but quantity is 4 short.
END/2/F2 is missing label
END/4/F5 is missing label
END/3/F4 is missing label, (same as END/4/F5)
END/3/S1 is incorrectly labeled as END/1/S1
There is a little bit of interference between END/4/F3 and END/4/F4.  I confirmed that it exists in the SketchUp model as well.
END/5/S2 and END/5/S3 are identical.  END/5/F2 and END/5/F3 should be identical, but they aren't.
Step 19: INT-A/2/F5 is missing label
Panel 032 should have INT-B/6/P2 label
INT-B/3/F1 is missing and INT-B/3/F2 is missing label
INT-B/4/F2 and INT-B/4/P2 are missing
INT-B/5/F2 INT-B/5/P2 are missing.  The castellation is asymmetric by about 2.9mm which makes assembly difficult and means that INT-B/5/F1 isn't the same as INT-B/3/F1
INT-B/6/F3 is missing and there are 2 of INT-B/6/F2
Step 20:  INT-A/PK should be quantity of 4.  Two parts are stacked together.  This can be seen on the pdf if you zoom in really close, but isn't made clear otherwise.
SKI/C and SKI/D:  The spacing between the notches is off by about 10.5mm.

Comments:
Please let me know if I should post these to another section of the git.

I noted a few instances where parts with different labels are actually identical.  Whether or not this is appropriate is probably a matter of opinion.  My inclination would be to make them the same part number so that there is more flexibility when nesting parts and is more in line with the idea of modularity.  A counter argument is that it might make assembly more intuitive if parts in a sub-assembly all have the same prefix.

Because of the way the PEGs are installed, the length of the connectors determines the center to center spacing of the frames.  This results in a spacing of 1199.5mm  I suspect this should be 1200mm.  Additionally, The length of "CONNECTOR" disagrees with the upper connectors "C-03"

Perhaps we can identify the locations to pre-drill holes for screws.  This might require a tool change on the router, but for some routers, this is trivial.  If the holes are on a separate layer, then it should be easy to not drill them on the CNC if that is the preference.  This would at least give some guidance as to the proper number of screws to use per panel.

I would like to see some support around the perimeter of all the skin panels so that the joint doesn't separate under load.  This was done very nicely where FLOOR/1 meets FLOOR/2, but this detail was left out of the walls, ceiling, roof and corners.  Because of the globally applied tolerance, I'm doubtful that the dovetails will transfer any meaningful load before some other part of the structure yields.  I think laminating reinforcers, like is done at the joints of the super box, is a more robust approach for shear and tensile loads.

Best Regards,
-jed

claytonprest, 2018-02-20:
Hi Jed,

This is absolutely the right place to post these issues. This is really excellent feedback and incredibly helpful that you've picked up on these errors and inconsistencies. We are building dedicated Wikihouse design software (to be freely available on the web) which should reduce human error like this in the near future. In the meantime thought, Github repos and CAD remain the platform - so we really value all your assistance here.

Enjoying looking around your Onshape model too - fantastic work! I've posted responses to your comments below, and now updated the cutting files and Assembly manual in the repo as a result.

_I could not open MicroHouse_othercomponents_v0.5.dxf with any of the half dozen programs I tried._

That is very odd. I haven't had any issues with this, and haven't had anyone report this before. It should open successfully in the latest version of draftsight, Autocad or Rhino or any  CAD software that can read DXF.

_Step 0: What size should the rails be?_

We nominally suggest 75mm wide for this model. You'll need to work with an structural engineer to determine the correct depth. I've added this note to the assembly guide.

_Step 2 and 3: F2 and F6 labels are swapped. ( I think F1 should be changed and F2 and F6 should be the same part.)_

I see your notes below but we prefer to keep them as unique parts. It might not make sense here on a perfectly symmetrical design like this, but the cyclical numbering is better logic for the Wikihouse software we're developing as well as for assembly by humans. Why do you thing F1 should be changed?

_Step 4: SKI/B, C, and D are left out of the manual and SKI/B needs to be installed on the first frame you raise._

Ski-B does need to be installed on the first frame and last frames only. I've added a note in Assembly Manual for SKI-C and D installation.

_F3 = F5, R1 = R2, R3 = R5_

After checking, I believe these are correct and match the assembly manual. What's your reasoning for this? Is it possible you've been assembling back to front?

_Step 7: Panel 009: ROOF/4 should be labeled EXWALL/4_

Well spotted. Thanks I have corrected this in the repo file commit.

_Step 9: The UNDER-X pieces need labels. There should be a FLOOR/4 for where UNDER/4 goes._

You're right there should be a variant FLOOR/4 to accommodate the Under/4 component. It seems there is a sheet missing as only 8x FLOOR/1 parts are included. As a result I have now added Sheet 035 to the cutting set.

_Step 10: I think CEIL/2 and CEIL/4 are the same as ROOF/5, but quantity is 2 short._

Yes, this is clearly an error on our part. I have added two more components (on new sheet 035) and corrected cutting set to CEIL/4 for all these. Assembly manual has been updated too.

_Add notes for interior and exterior trim pieces._

Fair point. We have now been doing this for subsequent projects, showing an additional step to install the trim.

_Step 11b: END/2/F1 is missing from DXF. It is the same as END/1/F1, but quantity is 4 short._

Yes END/2/F1 is missing, I have now added it on Sheet 026. Labels were also swapped on END/1/F parts and did not match the Assembly manual. The quantity is 2 short as you say. Fixed this shortage by copying part over to Sheet 023 as well.

_END/2/F2 is missing label_

Label now added.

_END/4/F5 is missing label. END/3/F4 is missing label, (same as END/4/F5)_

These parts may be too small to label / engrave. But I have added it anyway. They're actually not essentially required.

_END/3/S1 is incorrectly labeled as END/1/S1_

Corrected in the cutting set.

_There is a little bit of interference between END/4/F3 and END/4/F4. I confirmed that it exists in the SketchUp model as well._

Adjusted the length of END/4/F4 to fix this.

_END/5/S2 and END/5/S3 are identical. END/5/F2 and END/5/F3 should be identical, but they aren't._

Thanks, this has been fixed.

_Step 19: INT-A/2/F5 is missing label_

Just too small to realistically engrave labels on that one I'm afraid.

_Panel 032 should have INT-B/6/P2 label_

Done.

_INT-B/3/F1 is missing and INT-B/3/F2 is missing label_

Added on Sheet 034.

_INT-B/4/F2 and INT-B/4/P2 are missing_

I think the cutting set incorrectly assumes INT-B/4/P2 and INT-B/4/P1 are identical, which they aren't. There are two copies of INT-B/4/F3 which is identical

INT-B/5/F2 INT-B/5/P2 are missing. The castellation is asymmetric by about 2.9mm which makes assembly difficult and means that INT-B/5/F1 isn't the same as INT-B/3/F1

Issue has been fixed now.

_INT-B/6/F3 is missing and there are 2 of INT-B/6/F2_

I see there are 2 of INT-B/6/F2, when they should be different. This has been corrected (see INT-B/6/F4). I have also added the missing INT-B/6/F3.

_Step 20: INT-A/PK should be quantity of 4. Two parts are stacked together. This can be seen on the pdf if you zoom in really close, but isn't made clear otherwise._

Corrected in cutting files.

_SKI/C and SKI/D: The spacing between the notches is off by about 10.5mm._

Very odd. Thanks for picking up on this. It's been fixed now

You make a valid observation about
I noted a few instances where parts with different labels are actually identical. Whether or not this is appropriate is probably a matter of opinion. My inclination would be to make them the same part number so that there is more flexibility when nesting parts and is more in line with the idea of modularity. A counter argument is that it might make assembly more intuitive if parts in a sub-assembly all have the same prefix.

The centre-to-centre frame spacing of 1199.5mm you may have experienced in your virtual model is a result of pre-applied CNC manufacturing tolerance of 0.5mm inset on all components. In the reality of construction this doesn't really happen and this little bit of tolerance is very helpful during assembly.

It's a good suggestion to identify the locations to pre-drill holes for screws, and we actually are already doing this now on all current projects. They are on their own layer, and regularly set out at the recommend 150mm spacing, so can either be pre-drilled or just marked by 'dinks'.
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
jedroach, 2018-03-02:
Hello Clayton

Thanks for the feedback.

The problem with the _MicroHouse_othercomponents_v0.5.dxf_ appears to be a problem with how github is handling that dxf.  I originally downloaded that file individually using the "raw" button and that resulted in a file that was 23MB and wouldn't open.  When I downloaded the entire repo as a zip it worked fine.  Now that I can access that file, I'll work on giving it the same treatment as the chassis components.

_Step 2 and 3: F2 and F6 labels are swapped. ( I think F1 should be changed and F2 and F6 should be the same part.)
I see your notes below but we prefer to keep them as unique parts. It might not make sense here on a perfectly symmetrical design like this, but the cyclical numbering is better logic for the Wikihouse software we're developing as well as for assembly by humans. Why do you thing F1 should be changed?_

This is just more of my theory about minimizing unique parts.  If F1 had the same gender connector on both ends, then F2 and F6 would be identical parts.  However, I accept your reasoning for unique parts, so you can ignore.

I'm looking forward to seeing more models.

BTW, I attempted to join the slack by going through the typeform, but nothing came of it.  Any suggestions?

Thanks,
-jed

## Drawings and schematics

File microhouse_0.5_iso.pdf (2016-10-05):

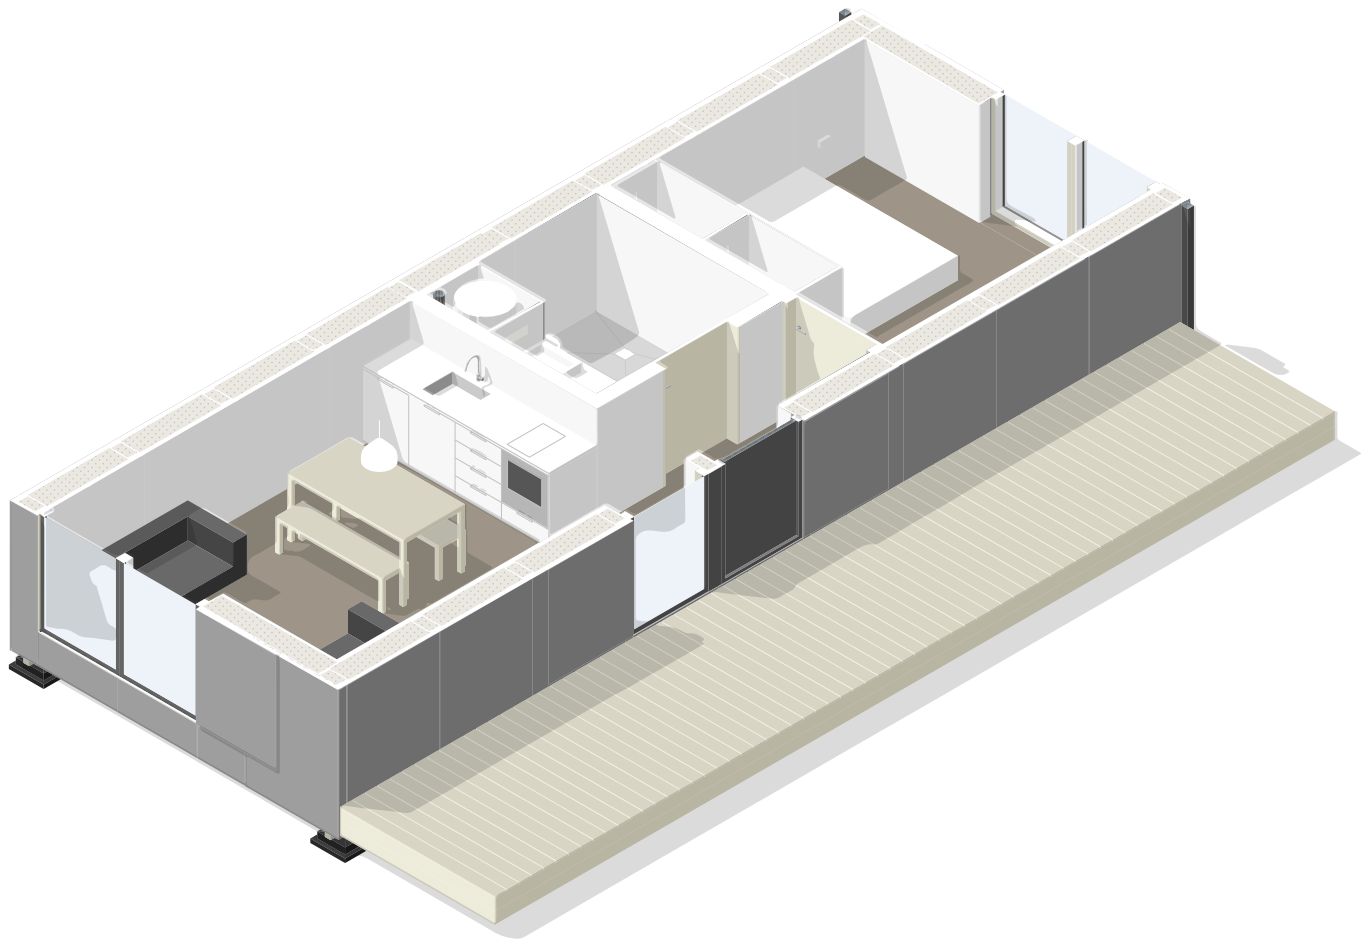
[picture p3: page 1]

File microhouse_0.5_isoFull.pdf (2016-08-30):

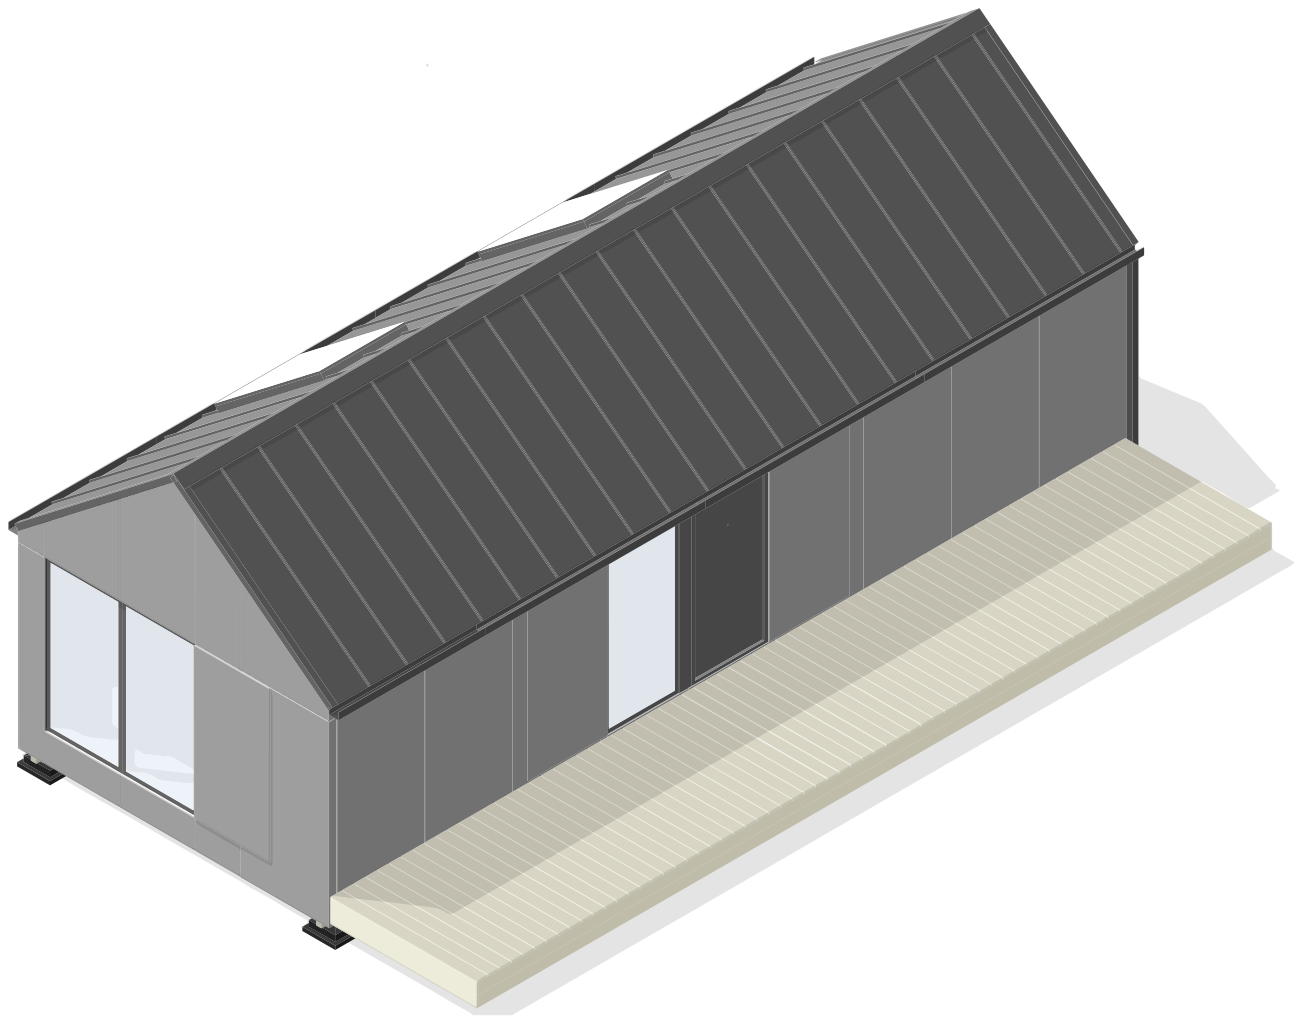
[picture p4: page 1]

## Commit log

2016-08-25 Wikihouse Wren v4.3.0
    A 1-bedroom 38m2 Microhouse design including full structural design and
    fit out, specification, CNC fabrication files, and costings.
    [MicroHouse Pilot Engine.xlsx, MicroHouse_othercomponents_v0.5.dxf, Microhouse_WRENchassis_v0.5.dxf]
2016-08-25 Revert "Wikihouse Wren v4.3.0"
    This reverts commit fc200c1cb8a4636b3549f59b073d0d6fee819ed5.
    [MicroHouse Pilot Engine.xlsx, MicroHouse_othercomponents_v0.5.dxf, Microhouse_WRENchassis_v0.5.dxf]
2016-08-30 Illustration and original files re-added
    Files added
    [MicroHouse Pilot Engine.xlsx, MicroHouse_othercomponents_v0.5.dxf, Microhouse_WRENchassis_v0.5.dxf]
2016-09-13 Missing connector slots added to reinforcers
    Missing connector slot has been added to the FRA-A/R1 and FRA-A/R2 components in the cutting files
2016-09-16 Missing labels added to spacers
    Missing spacer labels added to cutting files, many thanks to Paul Boden at University of Wolverhampton!
2016-10-03 Labels, sheathing panels amendments
    --- amendments courtesy of Paul Boden, University of Wolverhampton -----
    Part SKI/A – An additional double width slot has been included to allow them to connect to the R1,R2, F2 & F6 parts
    CEIL/1 – One of the slot was undersize in width, so copied and mirrored this slot to match the others. The discrepancy prevented the Ceiling panels to assemble.
    Additional amendment included on Sheet 3 – Part FRA-A/S4/EX, should now read FRA-A/S4/IN to match the assembly instructions.
2016-12-03 Edited DXF and SKP files of the chassis
    On the DXF: modified slots on the Ski/B to avoid interference with the
    reinforcers FRA-A/R2. Shortened an Ext. Wall part of the edge of the
    roof and copied it to cut the needed amount.
    On the SKP: Modified slots on Ski/A and Ski/B. Added missing part on
    one edge of external sheating, shortened same parts of the other side to
    avoid interference and added missing copies to the arrangement of parts
    to be cut. Align parts of End Walls.
2017-02-15 Add files via upload
    Spacer component numbering corrected to match assembly guide and cutting files.
2017-02-16 Terms of use added. Moved all geometry to z axis=0
    All geometry is now set to 0 on z axis. Erroneous parts removed.
2017-02-28 'Dog-bone' notches added to Spacer parts
2017-05-24 Corrected labelling of Reinforcers in Steps 2 & 3
    Correction to error/mismatch between assembly manual and cutting file labels on Reinforcer (R) parts.
2018-02-20 Big fixes and corrections!
    Latest working version of Microhouse chassis CNC files and corresponding update to Assembly Manual. A raft of amendments based on excellent (virtual) test build feedback from @jedroach - see his original issues and designer responses here: https://github.com/wikihouseproject/Microhouse/issues/13
